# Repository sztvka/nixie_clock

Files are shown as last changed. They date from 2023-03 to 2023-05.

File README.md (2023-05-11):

# Nixie Clock
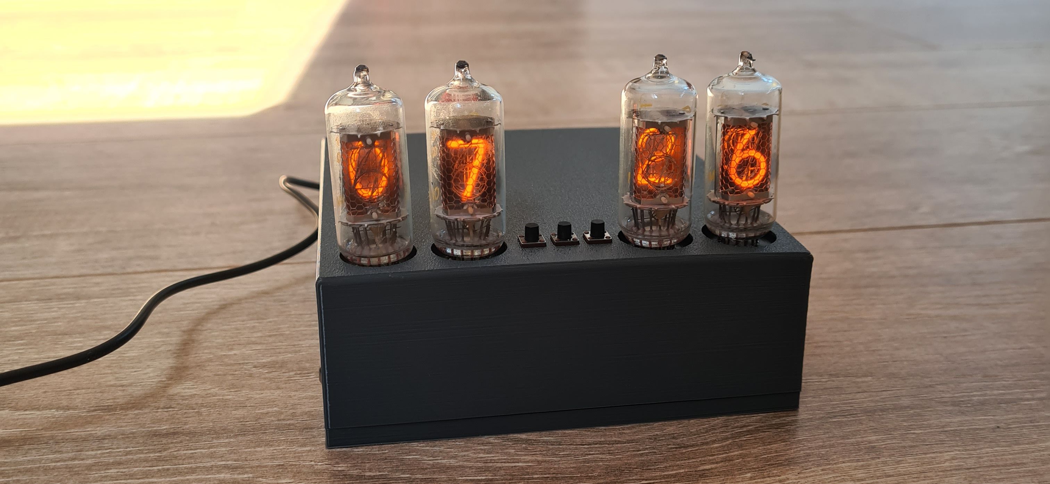
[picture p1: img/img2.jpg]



My attempt at reusing scrapped nixie tubes with their good old driver ICs. 

## Hardware
 - Z5730M Nixie Tubes
 - 74141 IC drivers 
 - 12-180V boost converter designed by [Nick de Smith](https://desmith.net/NMdS/Electronics/NixiePSU.html), modified to suit the design
 - STM32F411 MCU for control

 This design uses voltage-level shifters to properly drive Nixie Tube ICs. Altium Designer files, software and 3d models are available in their respective directories.

 ## Gallery

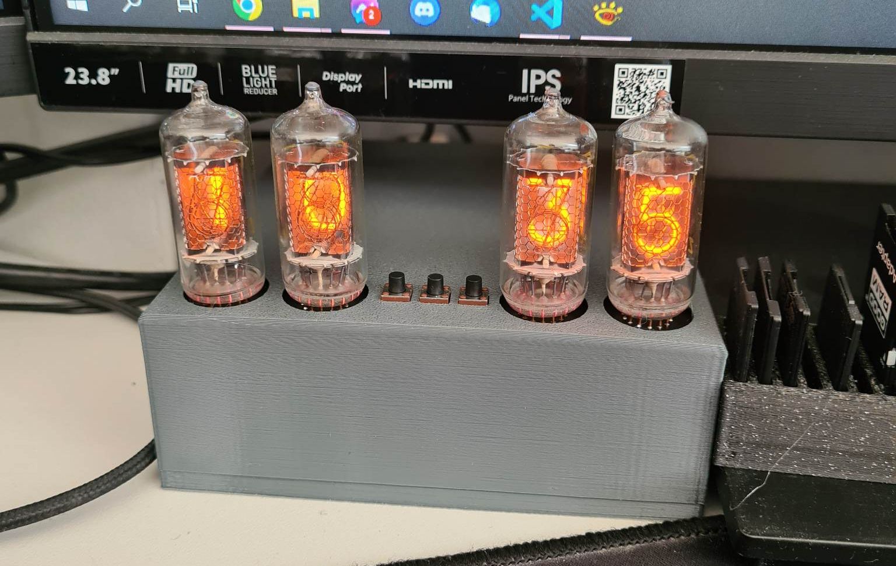
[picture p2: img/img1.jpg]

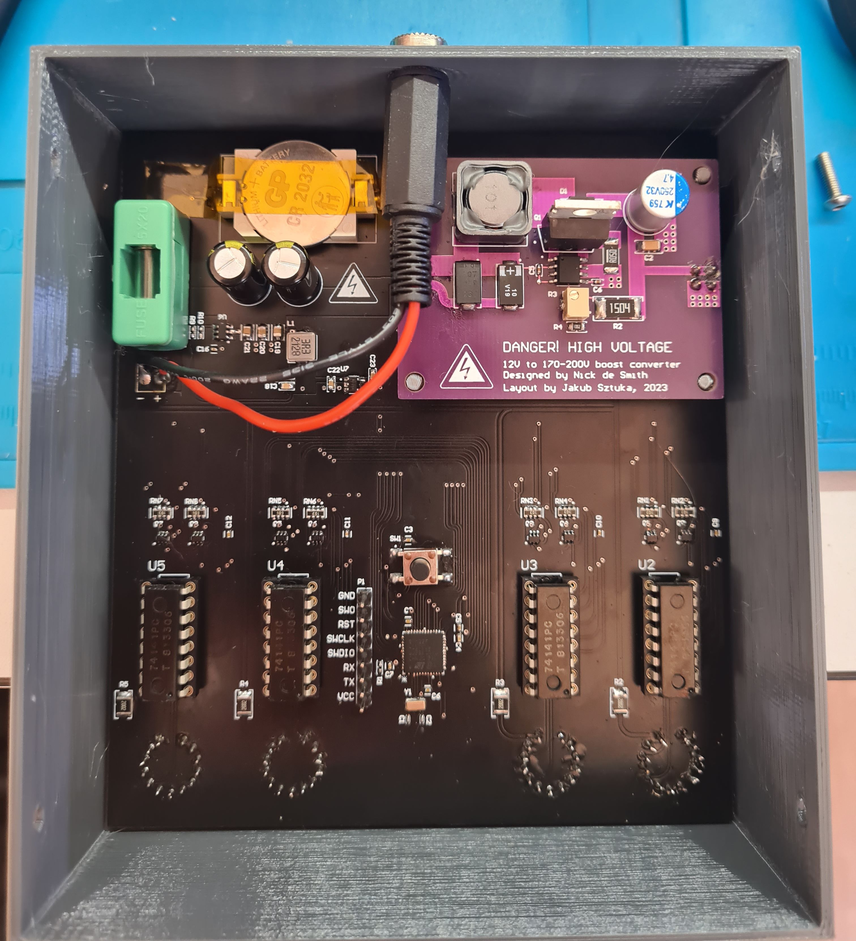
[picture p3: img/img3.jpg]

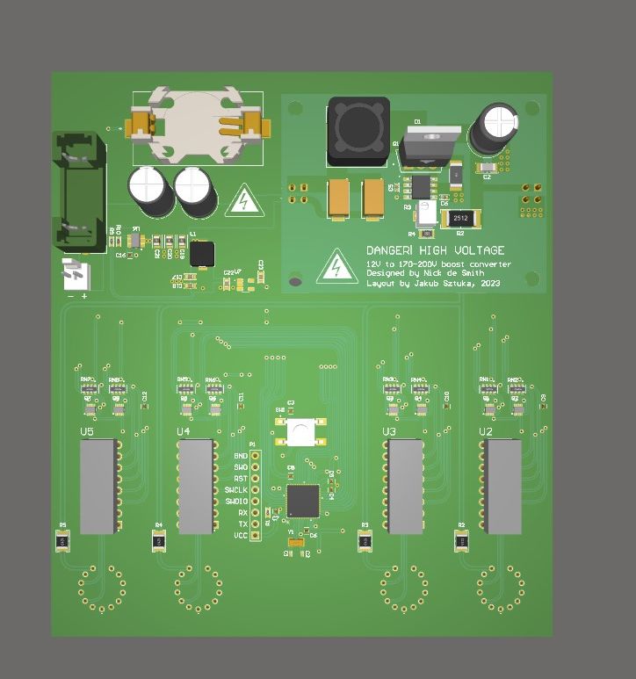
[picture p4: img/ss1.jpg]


## License

This project is licensed under the Creative Commons Attribution Share Alike 4.0 International - see the [LICENSE](LICENSE) file for details  
cc

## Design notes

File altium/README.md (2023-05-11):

# Altium design files
This project uses the [Celestial Altium Library](https://altiumlibrary.com/). If you wish to modify this PCB, it is required to have this lib included.

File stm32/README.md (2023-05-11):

# STM32 source code
This code is written for the STM32F411RE. The `stm32f411ccu6tr` directory contains a release version of the app, while `nucleo_f411re`contains a STM32 Nucleo board sample used for testing, without peripherals.

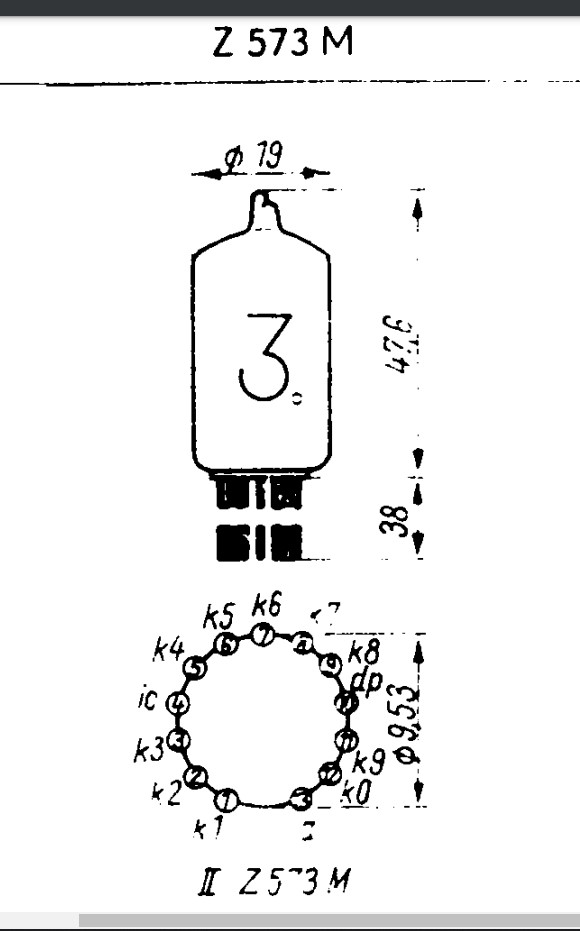
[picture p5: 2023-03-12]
altium/altium_hv/nixie_drawing.jpg

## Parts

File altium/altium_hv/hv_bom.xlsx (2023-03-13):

designator | Farnell | LCSC | Pcs
C1 |  | https://www.lcsc.com/product-detail/Tantalum-Capacitors_KEMET-T521D107M025ATE060_C212710.html | 4
C2 |  | https://www.lcsc.com/product-detail/Multilayer-Ceramic-Capacitors-MLCC-SMD-SMT_TDK-C3216X7R2E104KT0L0U_C76671.html | 4
C3 | https://dk.farnell.com/en-DK/kemet/a759ks475m2ebae496/kondensator-4-7-f-250v/dp/2886960 |  | 4
C4 |  | https://www.lcsc.com/product-detail/Tantalum-Capacitors_PANASONIC-35TQC10M_C147775.html | 2
C5,C6 |  | https://www.lcsc.com/product-detail/Multilayer-Ceramic-Capacitors-MLCC-SMD-SMT_TDK-CGA2B3X7R1V104MT0Y0F_C2802700.html | 2
D1 |  | https://www.lcsc.com/product-detail/Diodes-General-Purpose_Vishay-Intertech-ES2F-E3-52T_C145321.html | 2
J1,J2 |  | https://www.lcsc.com/product-detail/Pin-Headers_JST-Sales-America-RF-H042TD-1190-LF-SN_C160338.html | 2
L1 | https://pl.farnell.com/bourns/srr1280-101m/power-inductor-100uh-2-1a-shielded/dp/3774537?st=srr1280-101m |  | 4
Q1 |  | https://www.lcsc.com/product-detail/MOSFETs_Vishay-Intertech-IRF644PBF_C469331.html | 2
R1 |  | https://www.lcsc.com/product-detail/Chip-Resistor-Surface-Mount_YAGEO-PE2010FKM7W0R05L_C875711.html | 2
R2 |  | https://www.lcsc.com/product-detail/Chip-Resistor-Surface-Mount_YAGEO-AC2512FK-071M5L_C728137.html | 2
R3 |  | https://www.lcsc.com/product-detail/Variable-Resistors-Potentiometers_BOURNS-3214W-1-502E_C780196.html | 2
R4 |  | https://www.lcsc.com/product-detail/Chip-Resistor-Surface-Mount_YAGEO-RC0805FR-0710KL_C84376.html | 2
U1 |  | https://www.lcsc.com/product-detail/DC-DC-Controllers_Maxim-Integrated-MAX1771ESA-T_C407903.html | 1

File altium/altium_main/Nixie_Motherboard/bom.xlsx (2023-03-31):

DESIGNATOR | LCSC | QTY with extras for mishaps
BT1 | C70377 | 2
C1, C2 | C277478 | 100
C3, C5, C6, C7, C8, C9, C10, C11, C12, C13, C14, C15, C16 | C100072 | 100
C4 | C368809 | 50
C17, C18 | C86295 | 50
C19, C20, C21 | C15850 (https://www.lcsc.com/product-detail/Multilayer-Ceramic-Capacitors-MLCC-SMD-SMT_Samsung-Electro-Mechanics-CL21A106KAYNNNE_C15850.html) | 50
C22, C23 | C5673 (https://www.lcsc.com/product-detail/Multilayer-Ceramic-Capacitors-MLCC-SMD-SMT_Samsung-Electro-Mechanics-CL10A105KA8NNNC_C5673.html) | 50
J1, J2 | C2977590 | 10
L1 | C2847476 | 2
Q1, Q2, Q3, Q4, Q5, Q6, Q7, Q8 | C426871 | 15
R1, R6, R7, R8, R10 | C60490 | 100
R2, R3, R4, R5 | C620666 | 50
R9 | C5126096 | 100
RN1, RN2, RN3, RN4, RN5, RN6, RN7, RN8 | C29718 | 100
SW1, SW2, SW3, SW4 | C178262 | 6
U1 | C190642 | 2
U2 | C116592 | 5
U7 | C47773 | 5
XF1 | C717030 | 5
Y1 | C276424 | 2
DIP16-socket | C72130 | 5
Extra caps for crystal | C3034512 | 100
 | C3034517 | 100
 | C115539 | 100
 | C237417 | 100

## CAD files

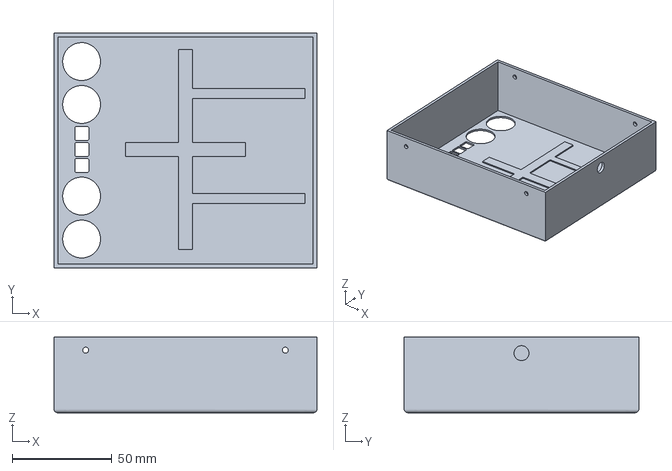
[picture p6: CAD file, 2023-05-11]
3d_model/Body1.3mf
131.8 x 117.6 x 37.9 mm

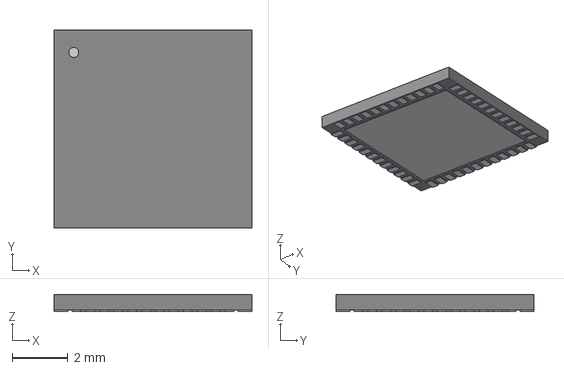
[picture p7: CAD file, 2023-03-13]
altium/altium_hv/Models/UFQFPN-48_7X7X0P55MM.step
7.11 x 7.11 x 0.612 mm

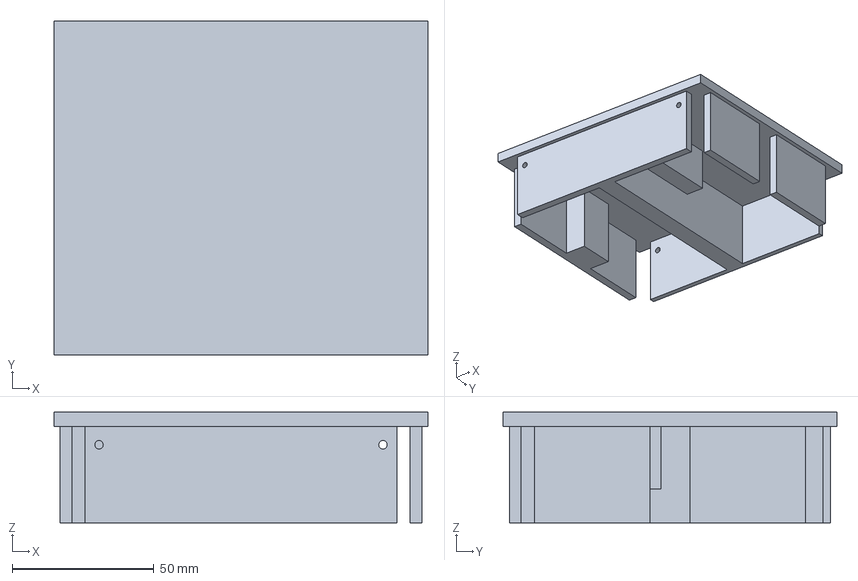
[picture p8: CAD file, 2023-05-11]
3d_model/Body2.3mf
131.7 x 117.5 x 39.0 mm

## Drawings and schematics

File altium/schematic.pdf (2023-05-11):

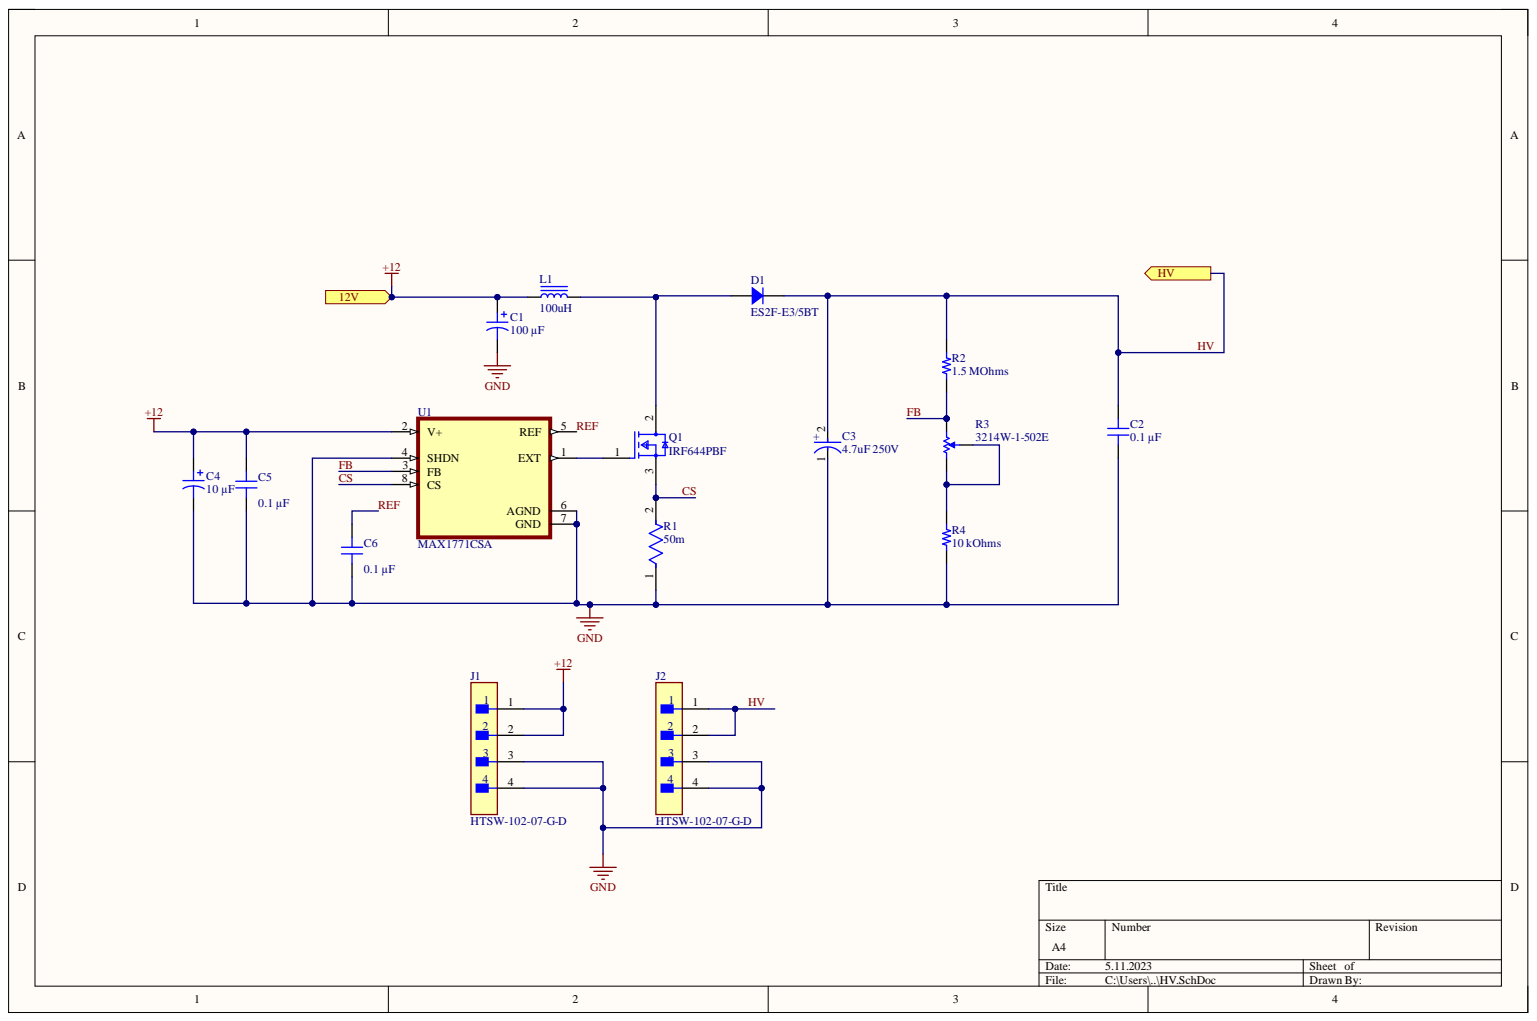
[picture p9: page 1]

SHDN 4

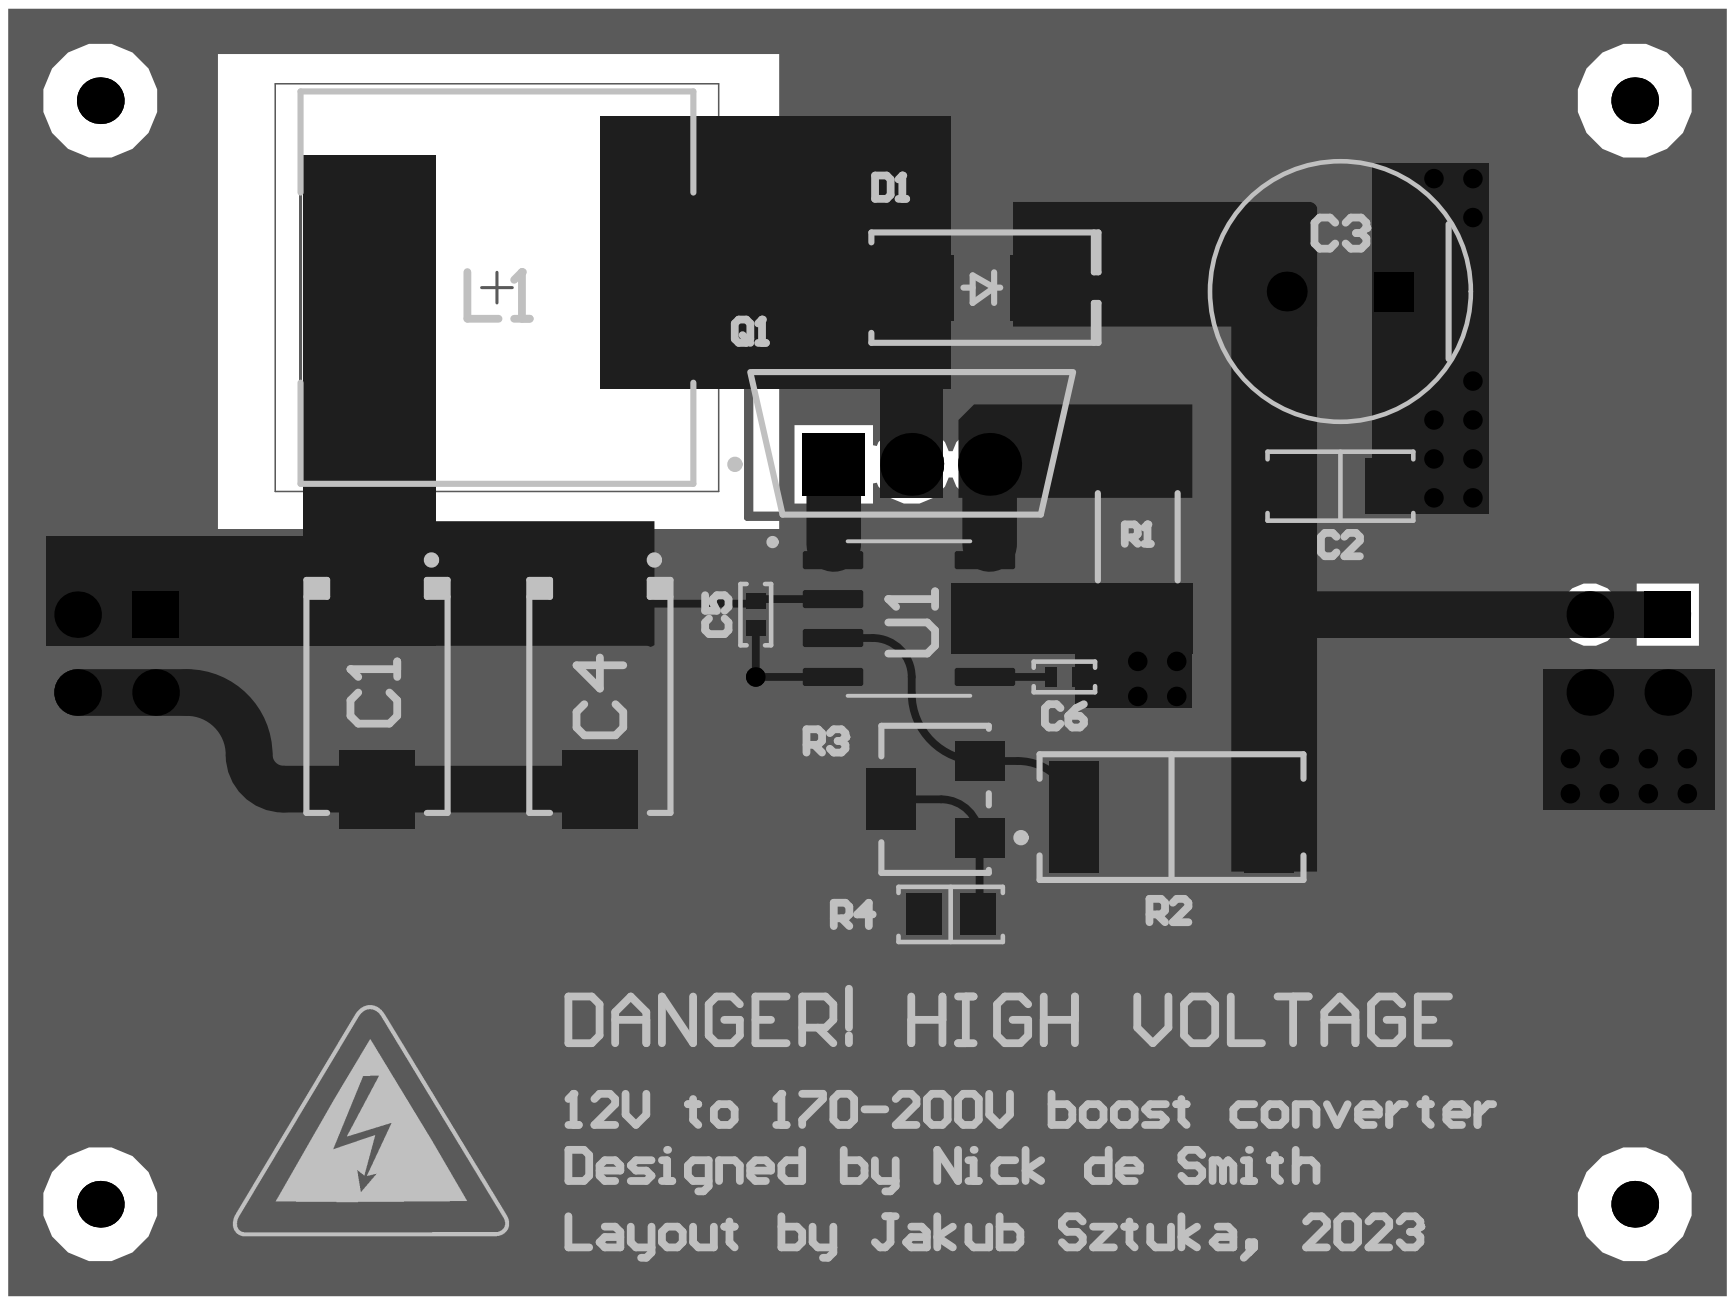
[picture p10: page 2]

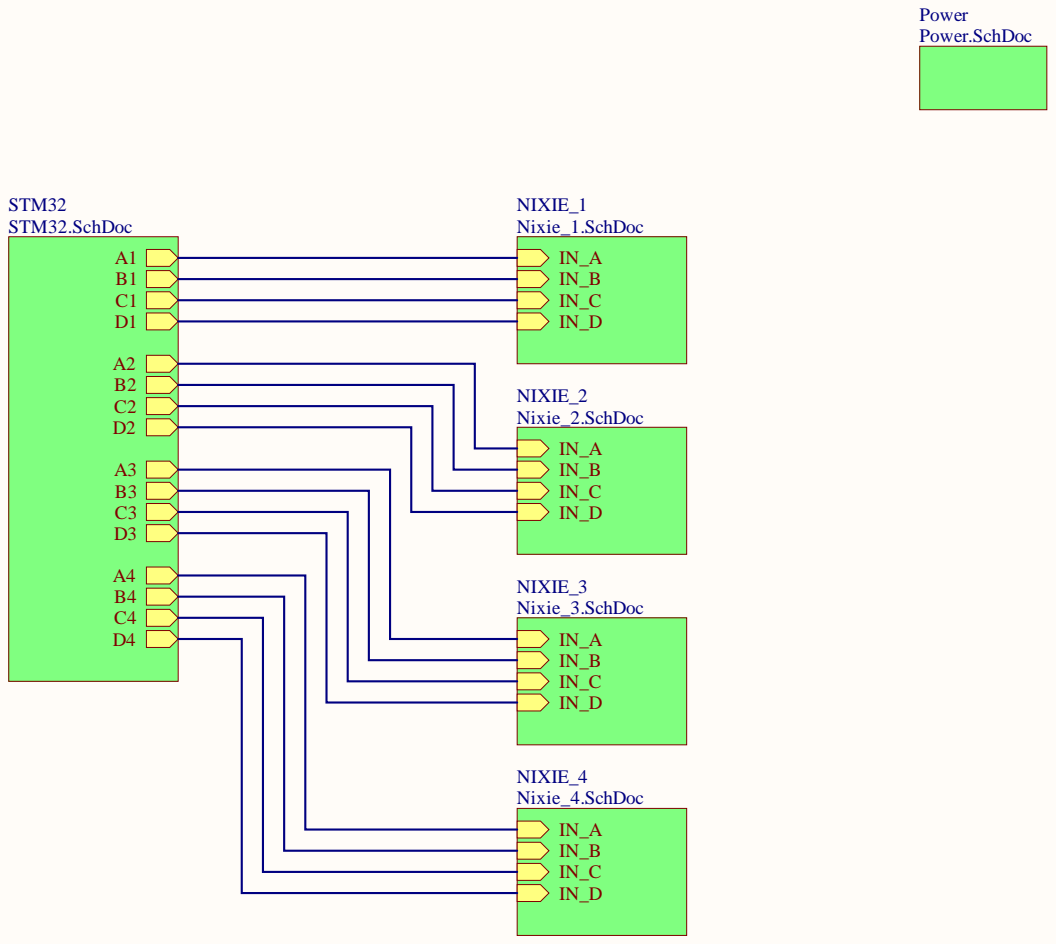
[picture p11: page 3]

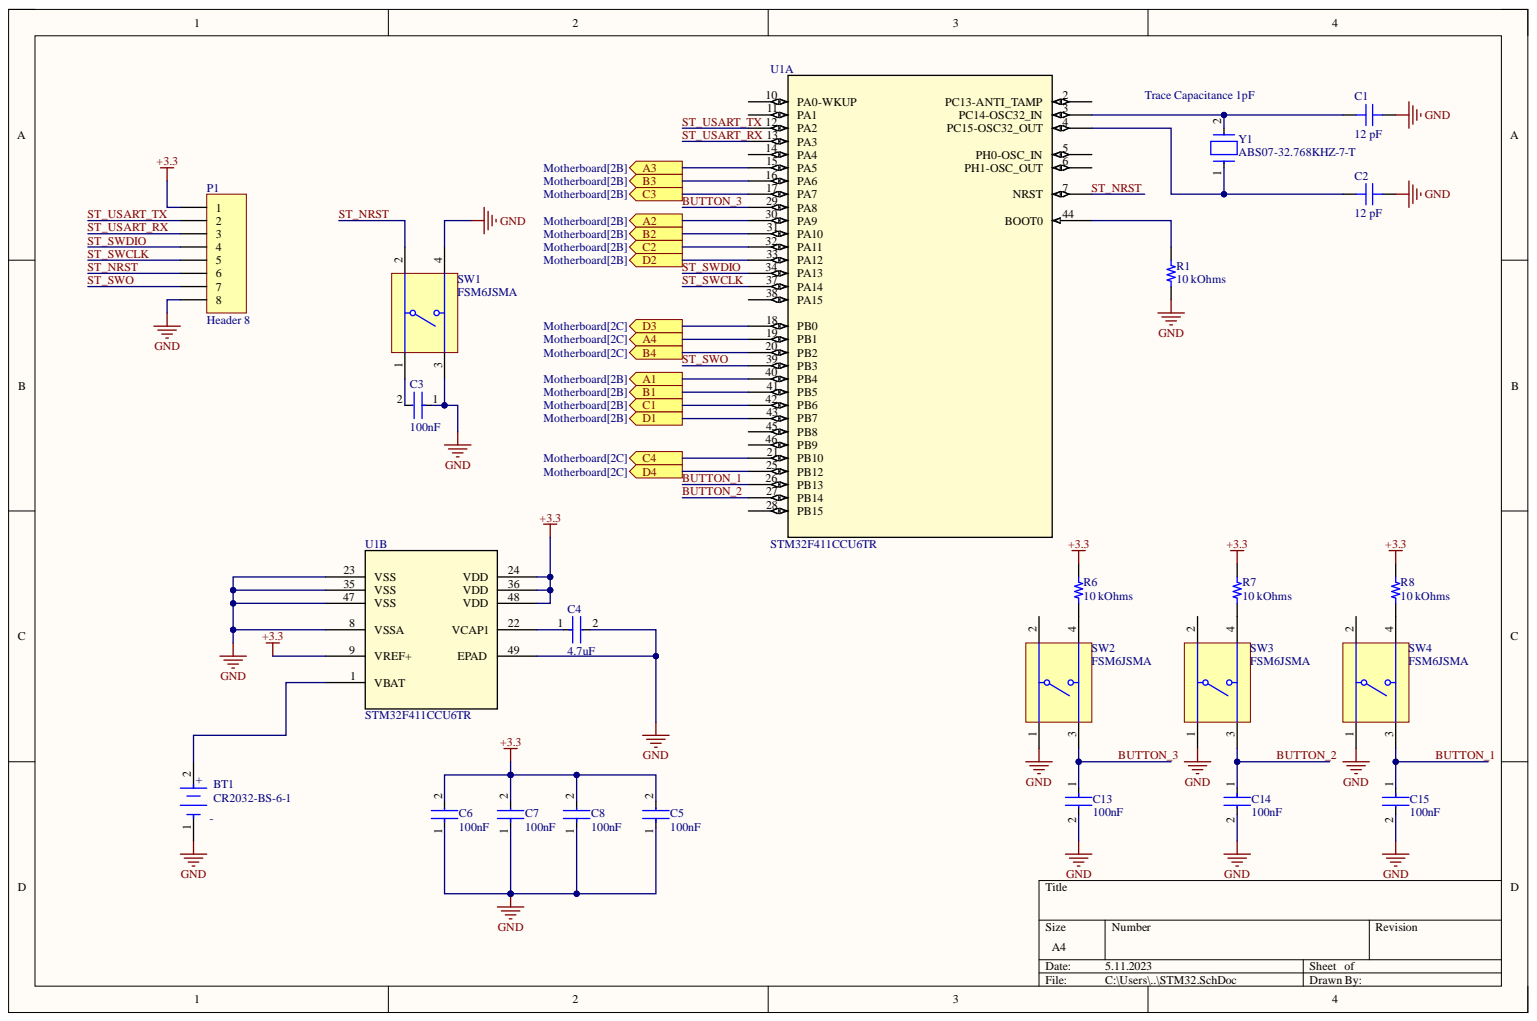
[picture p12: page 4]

3 5 | 3 6
4 7 | 4 8

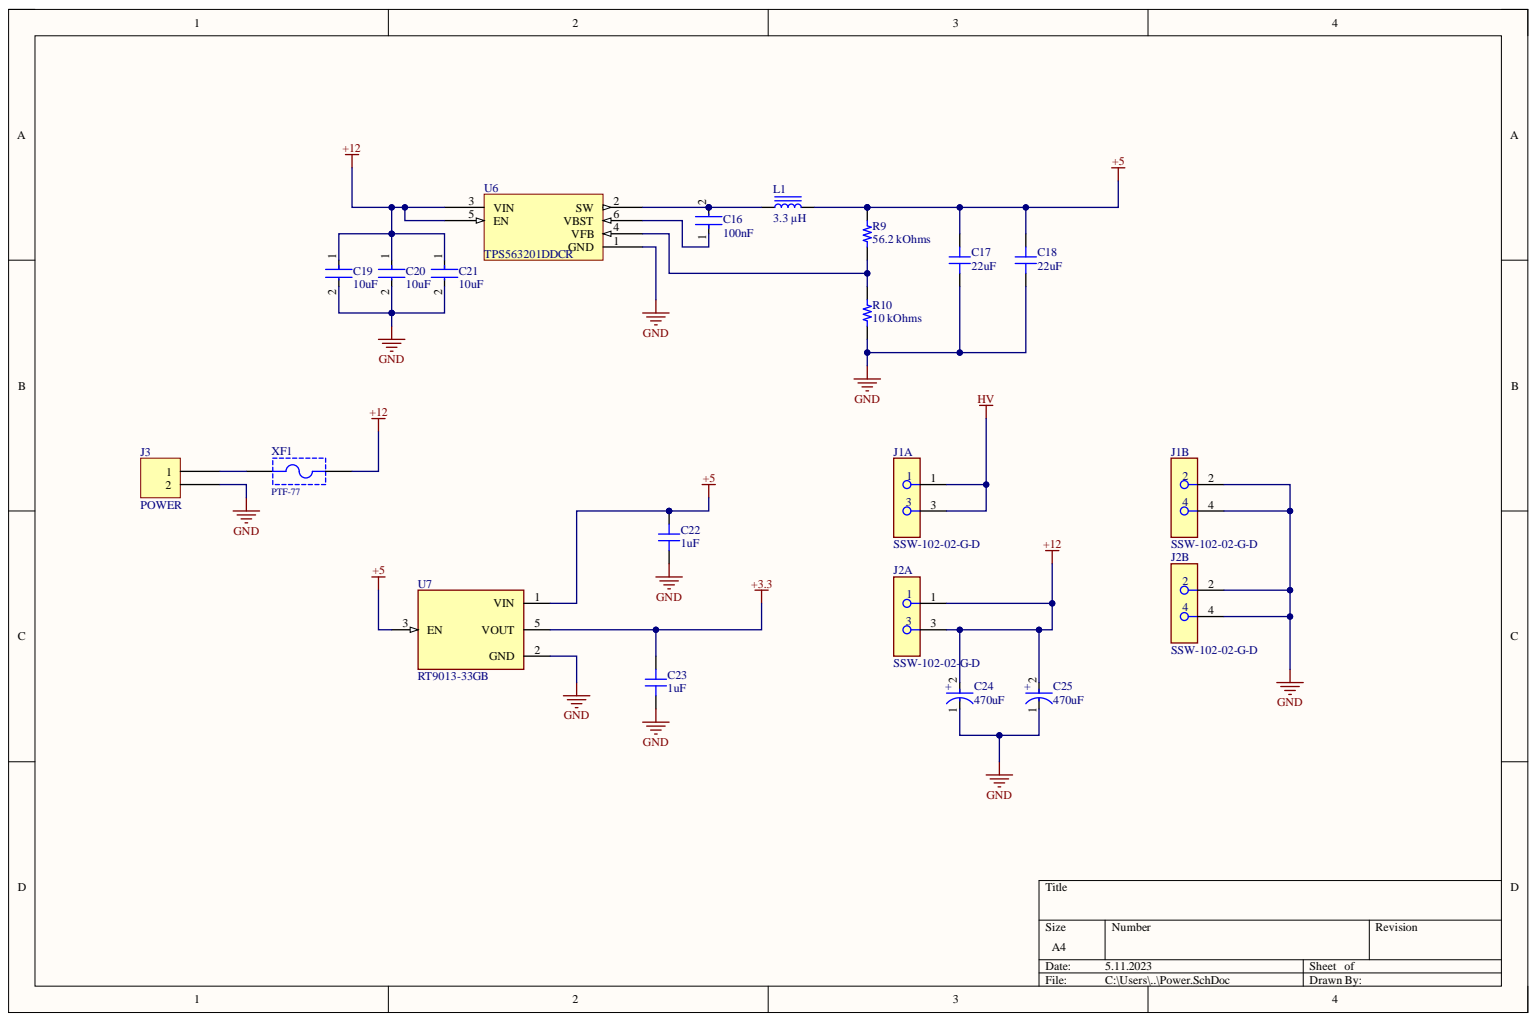
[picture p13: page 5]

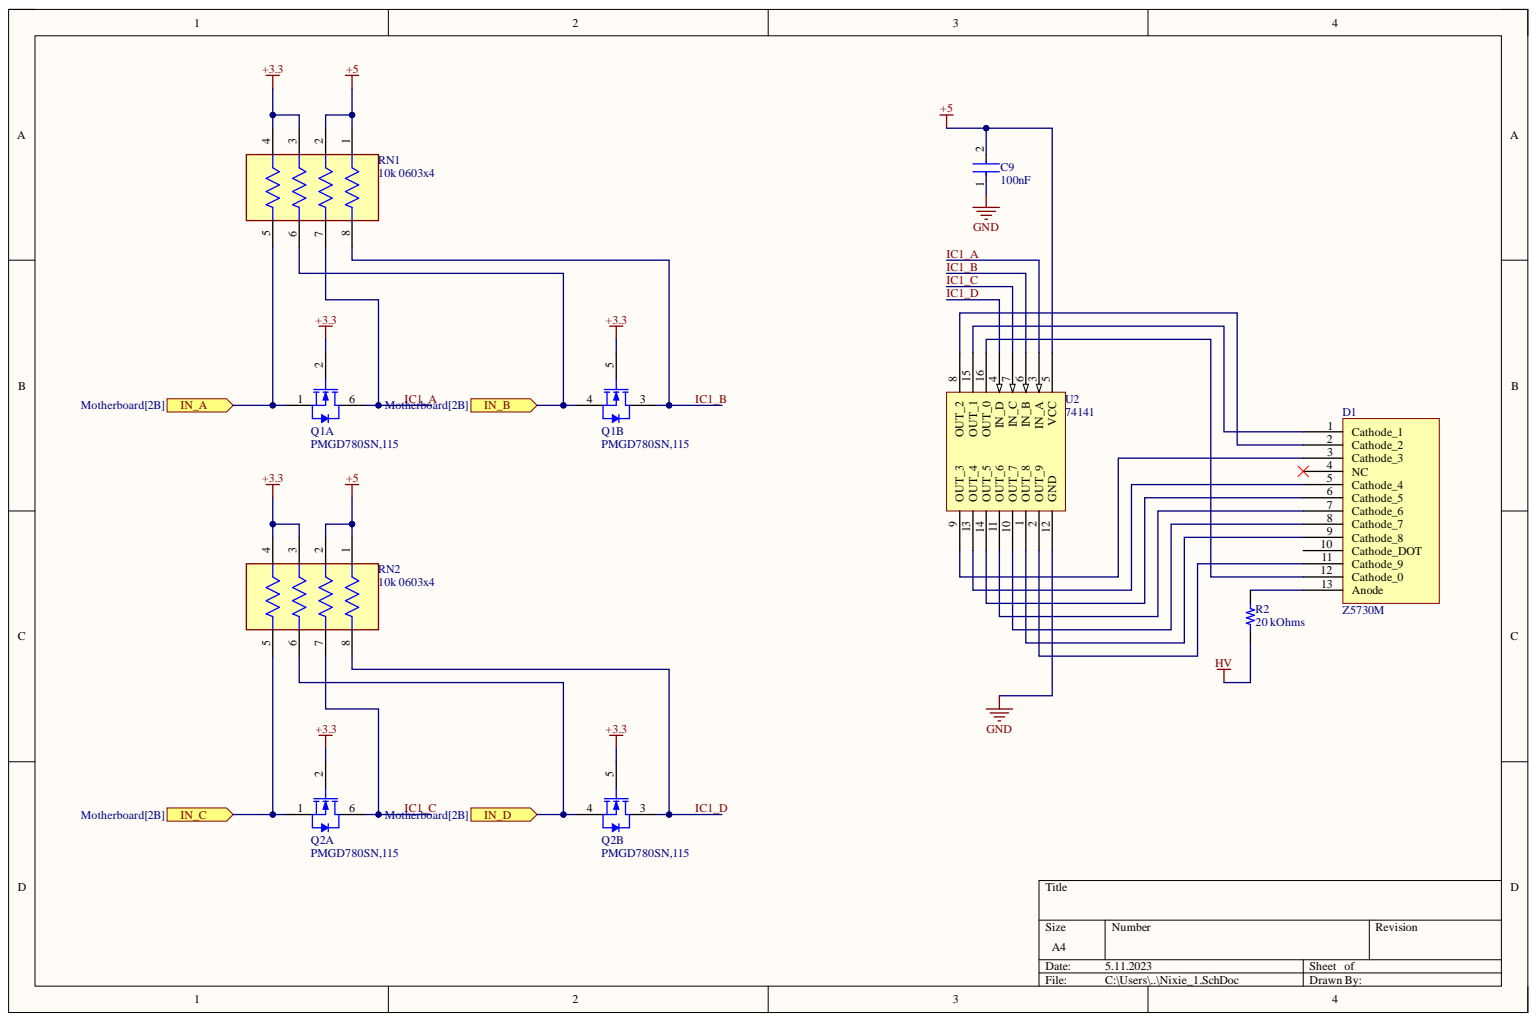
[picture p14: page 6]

1 0
1 1

R2 20
k O hms

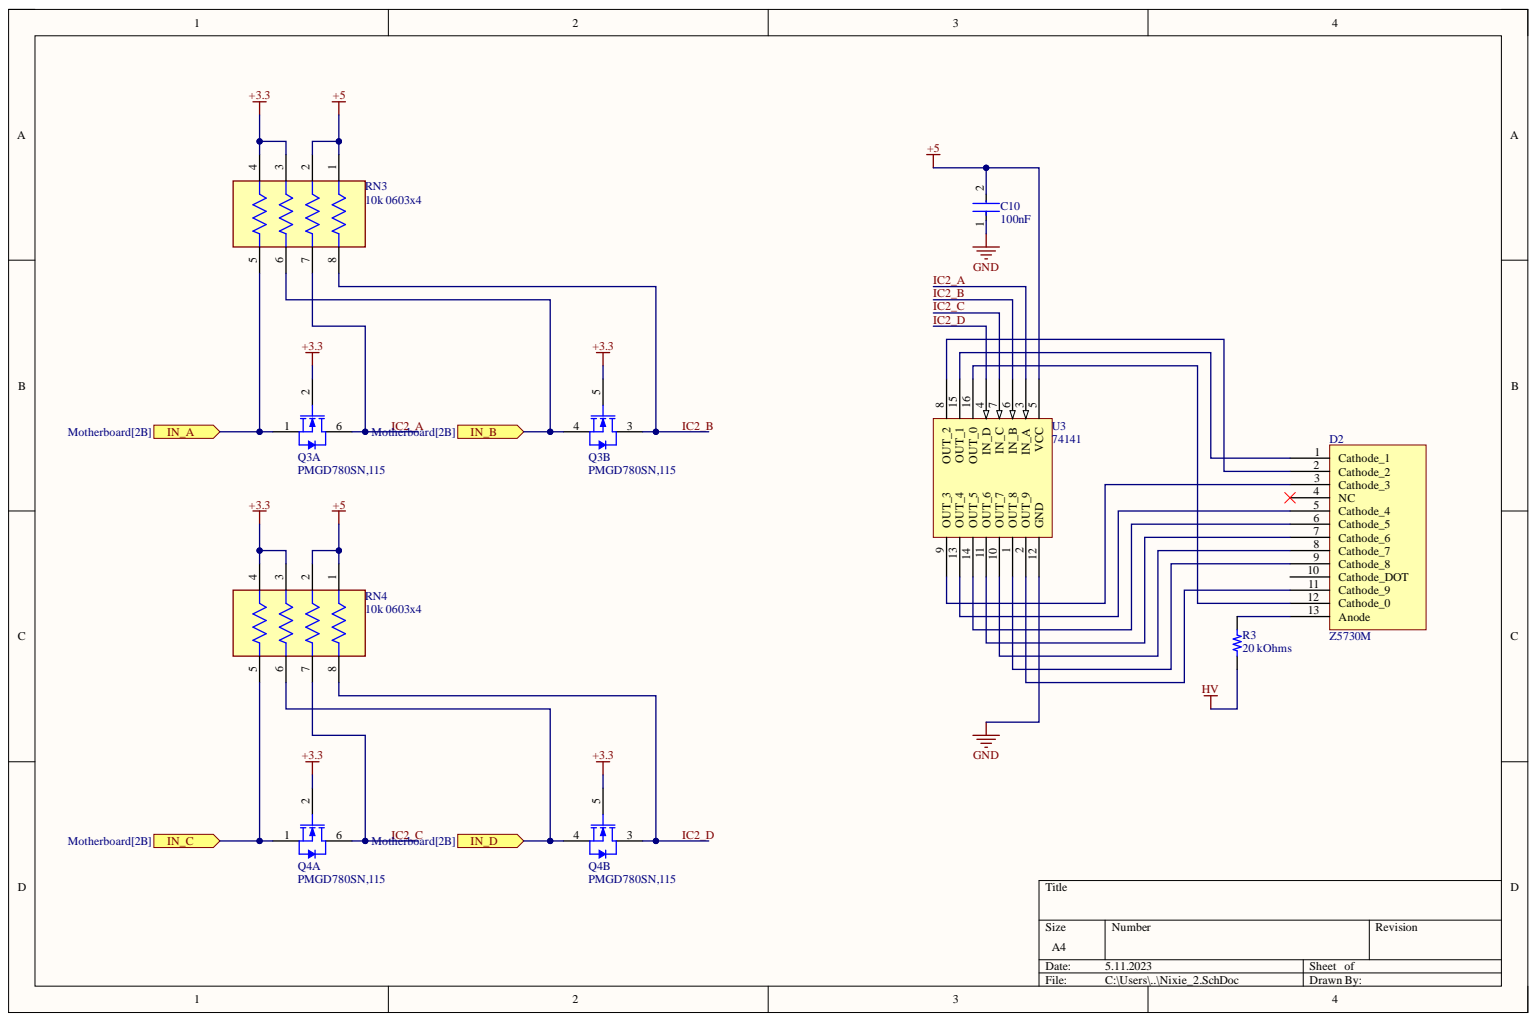
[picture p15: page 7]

1 0
1 1

R3 20
k O hms

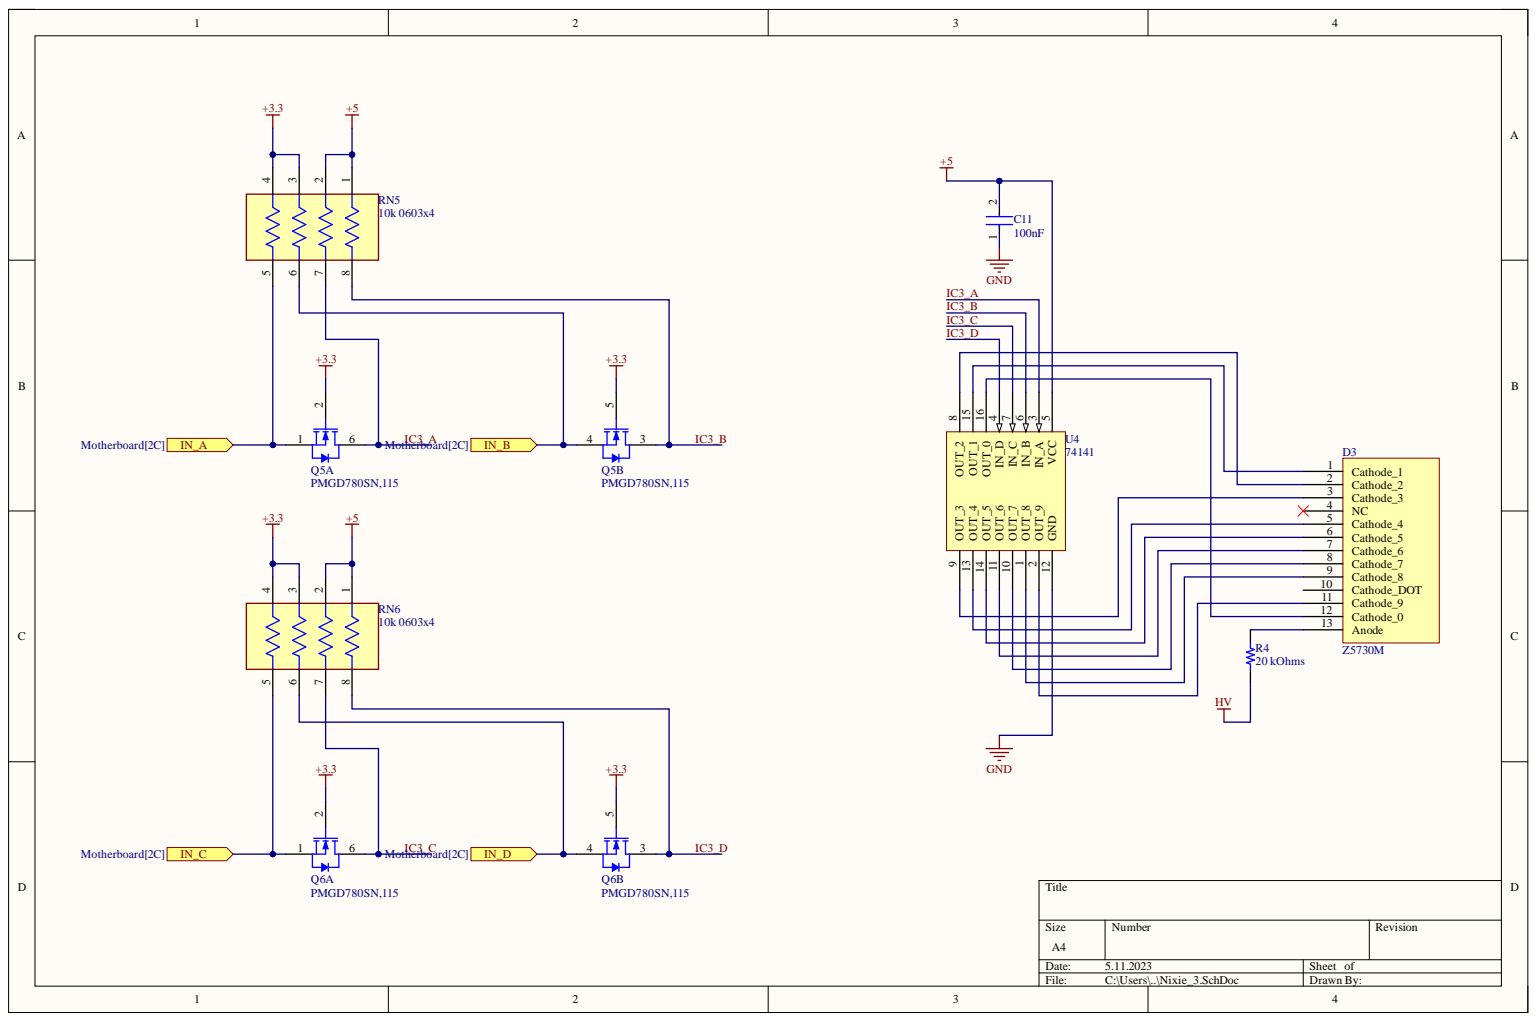
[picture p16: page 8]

1 0
1 1

R4 20
k O hms

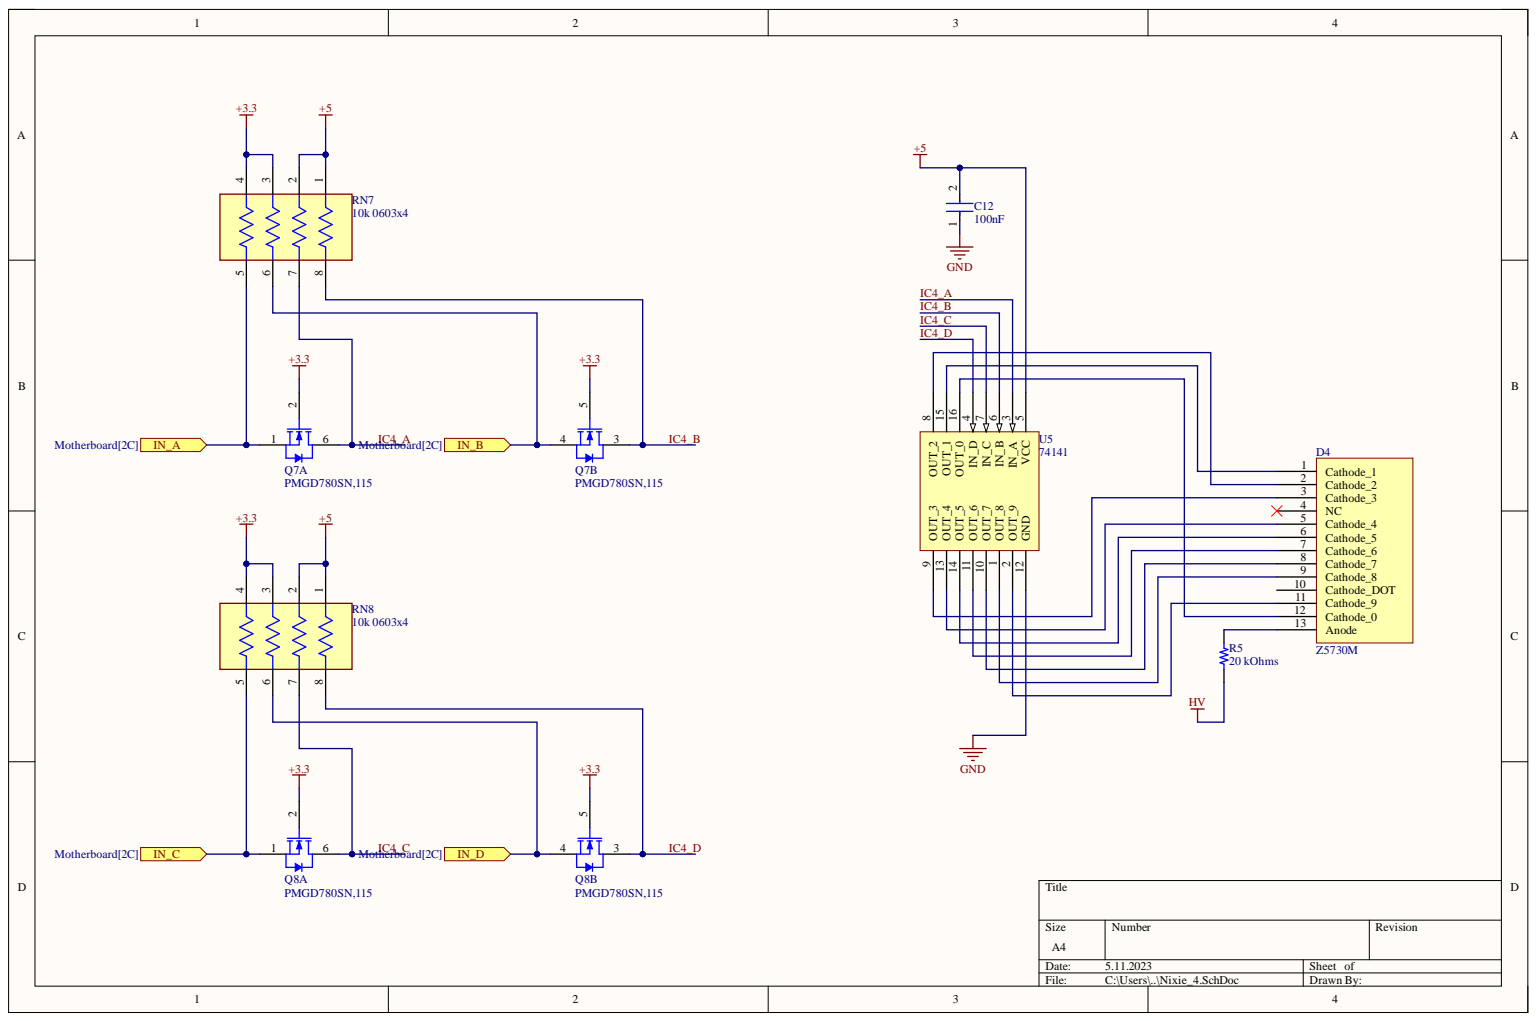
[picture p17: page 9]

1 0
1 1

R5 20
k O hms

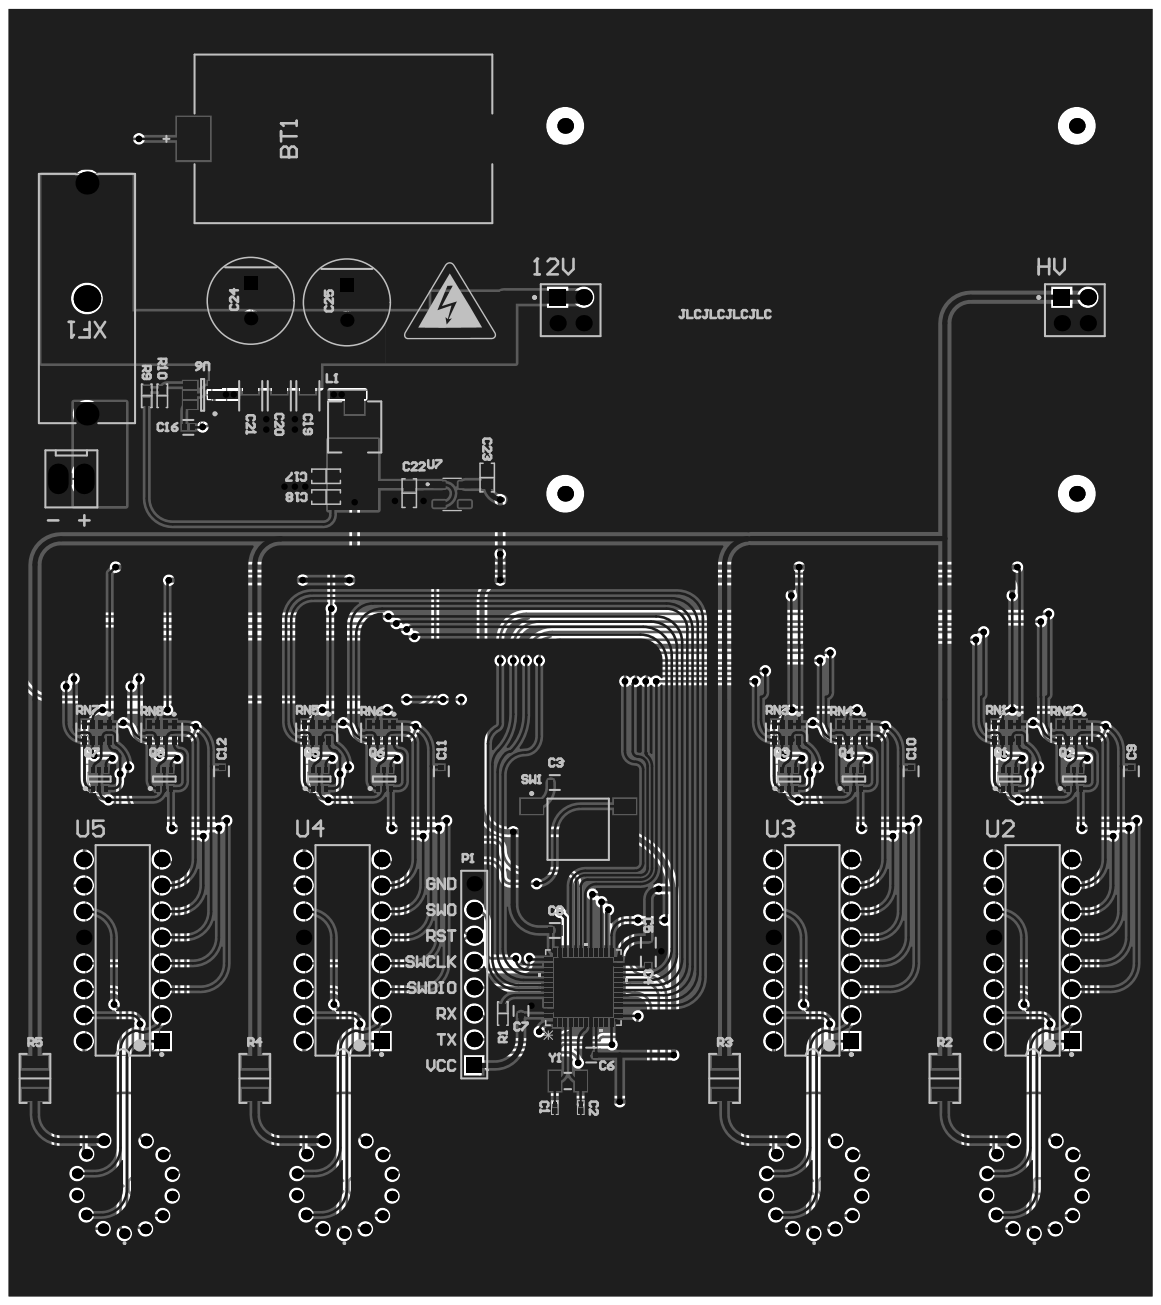
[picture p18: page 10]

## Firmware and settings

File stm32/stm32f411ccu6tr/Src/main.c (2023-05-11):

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
/* Includes ------------------------------------------------------------------*/
#include "main.h"

/* USER CODE BEGIN Includes */
#include "nixie.h"
/* USER CODE END Includes */

/* USER CODE BEGIN PD */
#define BUTTON_1_PORT GPIOB
#define BUTTON_1_PIN GPIO_PIN_13
#define BUTTON_2_PORT GPIOB
#define BUTTON_2_PIN GPIO_PIN_14
#define BUTTON_3_PORT GPIOA
#define BUTTON_3_PIN GPIO_PIN_8

/* USER CODE END PD */

RTC_HandleTypeDef hrtc;

UART_HandleTypeDef huart2;

/* USER CODE BEGIN PV */
RTC_TimeTypeDef RtcTime;
RTC_DateTypeDef RtcDate;
int8_t CompareMinutes = -1;
uint8_t CompareHours = 0;


Nixie_Pin pins[4][4] =
        {
                {   //Nixie A-D1
                        {GPIOB, GPIO_PIN_4}, //Schematic A1
                        {GPIOB, GPIO_PIN_5}, //Schematic B1
                        {GPIOB, GPIO_PIN_6}, //Schematic C1
                        {GPIOB, GPIO_PIN_7}  //Schematic D1
                },
                {   //Nixie A-D2
                        {GPIOA, GPIO_PIN_9},  //Schematic A2
                        {GPIOA, GPIO_PIN_10}, //Schematic B2
                        {GPIOA, GPIO_PIN_11}, //Schematic C2
                        {GPIOA, GPIO_PIN_12}  //Schematic D2
                },
                {   //Nixie A-D3
                        {GPIOA, GPIO_PIN_5},  //Schematic A3
                        {GPIOA, GPIO_PIN_6},  //Schematic B3
                        {GPIOA, GPIO_PIN_7},  //Schematic C3
                        {GPIOB, GPIO_PIN_0}   //Schematic D3
                },
                {   //Nixie A-D4
                        {GPIOB, GPIO_PIN_1},  //Schematic A4
                        {GPIOB, GPIO_PIN_2},  //Schematic B4
                        {GPIOB, GPIO_PIN_10}, //Schematic C4
                        {GPIOB, GPIO_PIN_12}  //Schematic D4
                }
        };


Nixie_IC Nixie1 = {
        .ports = pins[0],
        .value = 0
};
Nixie_IC Nixie2 = {
        .ports = pins[1],
        .value = 0
};
Nixie_IC Nixie3 = {
        .ports = pins[2],
        .value = 0
};
Nixie_IC Nixie4 = {
        .ports = pins[3],
        .value = 0
};


Nixie_Clock clock = { .tubes = {&Nixie1, &Nixie2, &Nixie3, &Nixie4} };


/* USER CODE END PV */

void SystemClock_Config(void);
static void MX_GPIO_Init(void);
static void MX_RTC_Init(void);
static void MX_USART2_UART_Init(void);
/**
  * @brief  The application entry point.
  * @retval int
  */
int main(void)
{
  /* MCU Configuration--------------------------------------------------------*/

  /* Reset of all peripherals, Initializes the Flash interface and the Systick. */
  HAL_Init();

  /* Configure the system clock */
  SystemClock_Config();

  /* Initialize all configured peripherals */
  MX_GPIO_Init();
  MX_RTC_Init();
  MX_USART2_UART_Init();
  /* Infinite loop */
  /* USER CODE BEGIN WHILE */
  while (1)
  {

      HAL_RTC_GetTime(&hrtc, &RtcTime, RTC_FORMAT_BIN);
      HAL_RTC_GetDate(&hrtc, &RtcDate, RTC_FORMAT_BIN); //need to read date for proper timekeeping
      if(CompareMinutes != RtcTime.Minutes)
      {
          CompareMinutes = (int8_t)RtcTime.Minutes;
          setNixieTime(&clock, &RtcTime);
      }
      if(CompareHours != RtcTime.Hours)
      {
          CompareHours = RtcTime.Hours;
          NixieShuffle(&clock);
      }


      if(HAL_GPIO_ReadPin(BUTTON_1_PORT, BUTTON_1_PIN)==GPIO_PIN_RESET){
            HAL_Delay(100);
            if(HAL_GPIO_ReadPin(BUTTON_1_PORT, BUTTON_1_PIN)==GPIO_PIN_RESET){
                RTC_TimeTypeDef adjTime = RtcTime;
                if(adjTime.Minutes==59){
                    adjTime.Minutes = 0;
                    adjTime.Hours = (adjTime.Hours+1)%24;
                }
                else adjTime.Minutes++;

                if (HAL_RTC_SetTime(&hrtc, &adjTime, RTC_FORMAT_BIN) != HAL_OK)
                 {
                      Error_Handler();
                 }

            }
      }

      if(HAL_GPIO_ReadPin(BUTTON_3_PORT, BUTTON_3_PIN)==GPIO_PIN_RESET){
          HAL_Delay(100);
          if(HAL_GPIO_ReadPin(BUTTON_3_PORT, BUTTON_3_PIN)==GPIO_PIN_RESET){
              RTC_TimeTypeDef adjTime = RtcTime;
              if(adjTime.Minutes==0){
                  adjTime.Minutes = 59;
                    adjTime.Hours = adjTime.Hours==0 ? 23 : adjTime.Hours-1;
              }
              else adjTime.Minutes--;

              if (HAL_RTC_SetTime(&hrtc, &adjTime, RTC_FORMAT_BIN) != HAL_OK)
              {
                  Error_Handler();
              }

          }
      }


    /* USER CODE END WHILE */

    /* USER CODE BEGIN 3 */
  }
  /* USER CODE END 3 */
}

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


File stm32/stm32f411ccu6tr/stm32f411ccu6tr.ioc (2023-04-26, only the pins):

Mcu.UserName=STM32F411CCUx
PA10.Signal=GPIO_Output
PA11.Signal=GPIO_Output
PA12.Signal=GPIO_Output
PA13.Signal=SYS_JTMS-SWDIO
PA14.Signal=SYS_JTCK-SWCLK
PA2.Signal=USART2_TX
PA3.Signal=USART2_RX
PA5.Signal=GPIO_Output
PA6.Signal=GPIO_Output
PA7.Signal=GPIO_Output
PA8.Signal=GPIO_Input
PA9.Signal=GPIO_Output
PB0.Signal=GPIO_Output
PB1.Signal=GPIO_Output
PB10.Signal=GPIO_Output
PB12.Signal=GPIO_Output
PB13.Signal=GPIO_Input
PB14.Signal=GPIO_Input
PB2.Signal=GPIO_Output
PB3.Signal=SYS_JTDO-SWO
PB4.Signal=GPIO_Output
PB5.Signal=GPIO_Output
PB6.Signal=GPIO_Output
PB7.Signal=GPIO_Output
PC14-OSC32_IN.Signal=RCC_OSC32_IN
PC15-OSC32_OUT.Signal=RCC_OSC32_OUT

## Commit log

2023-02-28 psu design
    [MAX1771CSA.SchLib, Nixie_clock.PrjPcb, SOIC127P600X175-8N.PcbLib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]
2023-02-28 POWER HV
    [Sheet1.SchDoc]
2023-03-01 pcb drc clean
    [HV.SchDoc, PCB1.PcbDoc]
2023-03-01 pcb file rename
    [HV_PCB.PcbDoc, Nixie_clock.PrjPcb, PCB1.PcbDoc]
2023-03-08 drc passing hv board complete
    [HV_PCB.PcbDoc, Nixie_clock.PrjPcb]
2023-03-08 component mismatch
    [HV.SchDoc, HV_PCB.PcbDoc]
2023-03-09 pcb finished and ordered
    [HV_PCB.PcbDoc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]
2023-03-12 nixie library
    [NIXIE.PcbLib, Nixie_clock.PrjPcb, Z5730M.SchLib]
2023-03-13 project restructurization, multi-board assembly
    [HV.SchDoc, HV_PCB.PcbDoc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]
2023-03-13 missed adds
    [HV.SchDoc, Motherboard.PcbDoc, Motherboard.SchDoc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]
2023-03-14 nixie schematic structurization
    [NIXIE.SchDoc, NIXIE_1.SchDoc, NIXIE_2.SchDoc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]
2023-03-14 todo fix power
    [Motherboard.SchDoc, NIXIE_1.SchDoc, NIXIE_2.SchDoc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]
2023-03-15 nixie step shifters
    [Motherboard.SchDoc, NIXIE_1.SchDoc, NIXIE_2.SchDoc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]
2023-03-19 pin mapping
    [Motherboard.PcbDoc, Motherboard.SchDoc, STM32.SchDoc]
2023-03-23 5v regulator
    [Nixie_Motherboard.PrjPcb, Power.SchDoc, Power.SchLib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]
2023-03-23 3.3v regulator
    [NIXIE.PcbLib, Nixie_Motherboard.PrjPcb, Power.SchDoc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]
2023-03-23 pcb rooms arrangement
    [Motherboard.PcbDoc]
2023-03-23 5v 3.3v regulator layout
    [MotherBoard.PcbDoc]
2023-03-25 nixie layout
    [MotherBoard.PcbDoc, NIXIE.PcbLib]
2023-03-25 nixie laid out with spacing
    [MotherBoard.PcbDoc]
2023-03-27 add caps to hv psu
    [MotherBoard.PcbDoc, Nixie_Motherboard.PrjPcb, Power.SchDoc]
2023-03-28 nixie footprint fixed and power
    [MotherBoard.PcbDoc, NIXIE.PcbLib, Power.SchDoc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]
2023-03-28 power complete
    [MotherBoard.PcbDoc, Nixie_1.SchDoc, Nixie_2.SchDoc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]
2023-03-28 DRC CLEAN PCB DONE
2023-03-31 bom update
    [MotherBoard.PcbDoc, Nixie_Motherboard.PrjPcb, STM32.SchDoc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]
2023-05-11 docs and github ci
    [Body1.3mf, Body2.3mf]

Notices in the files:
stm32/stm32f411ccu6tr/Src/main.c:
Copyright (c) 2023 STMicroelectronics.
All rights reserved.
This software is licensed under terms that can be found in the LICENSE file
